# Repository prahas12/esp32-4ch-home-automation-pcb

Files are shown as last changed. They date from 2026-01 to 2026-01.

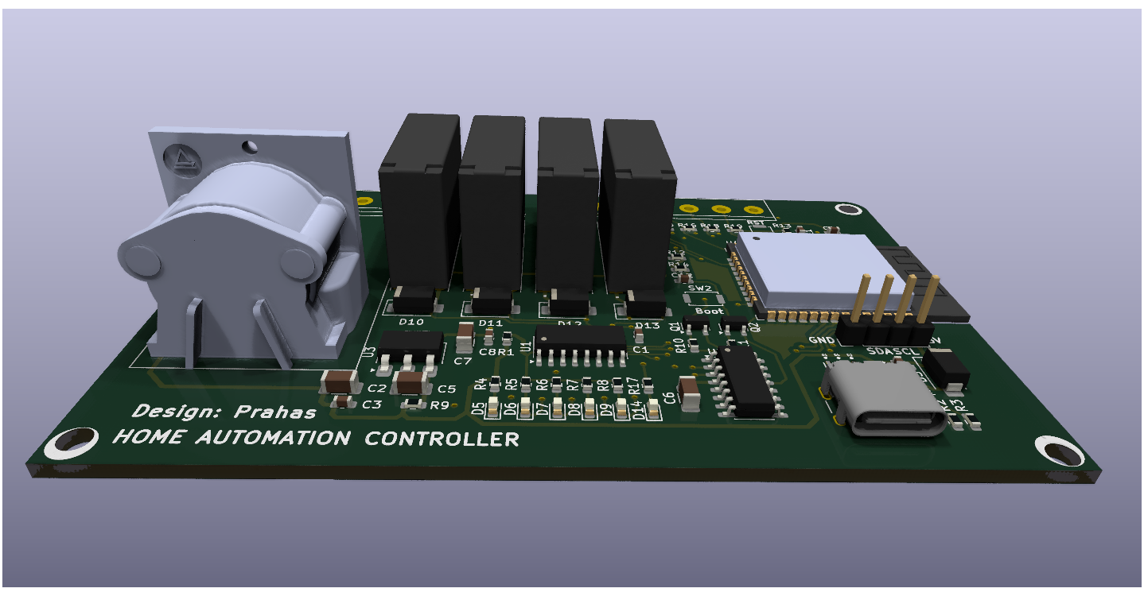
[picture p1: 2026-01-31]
home_automation.png

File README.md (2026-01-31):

# 4-Channel Home Automation PCB using ESP32

This repository contains the hardware design files for a **4-channel home automation system based on ESP32**, designed for reliable and safe control of electrical appliances using Wi-Fi.

The project focuses on practical IoT hardware design, including relay isolation, opto-isolated inputs, and an onboard AC-to-DC power supply.

---

## 🔧 Features

- ESP32-based Wi-Fi control (Web Server & MQTT supported)
- 4-channel relay outputs for AC appliance control
- Opto-isolated inputs for safe external switch interfacing
- Onboard AC-to-DC power module (HLK-PM03 or equivalent)
- Compact 2-layer PCB suitable for enclosure mounting
- Status LEDs for power and relay indication

---

## ⚙️ Hardware Used

- ESP32-WROOM-32 (Wi-Fi + Bluetooth MCU)
- 4 × SPDT Relays (5V)
- Optocouplers for isolated switch inputs
- AC to DC power module (HLK-PM03 or equivalent)
- Screw terminals for AC loads and inputs
- Discrete driver transistors, resistors, and protection components

---

## 🛠️ PCB Design Details

- Designed using **KiCad**
- 2-layer PCB for cost efficiency
- Proper isolation between high-voltage (AC) and low-voltage (ESP32) sections
- Wide copper traces for relay current handling
- Through-hole components used where mechanical strength is required

---

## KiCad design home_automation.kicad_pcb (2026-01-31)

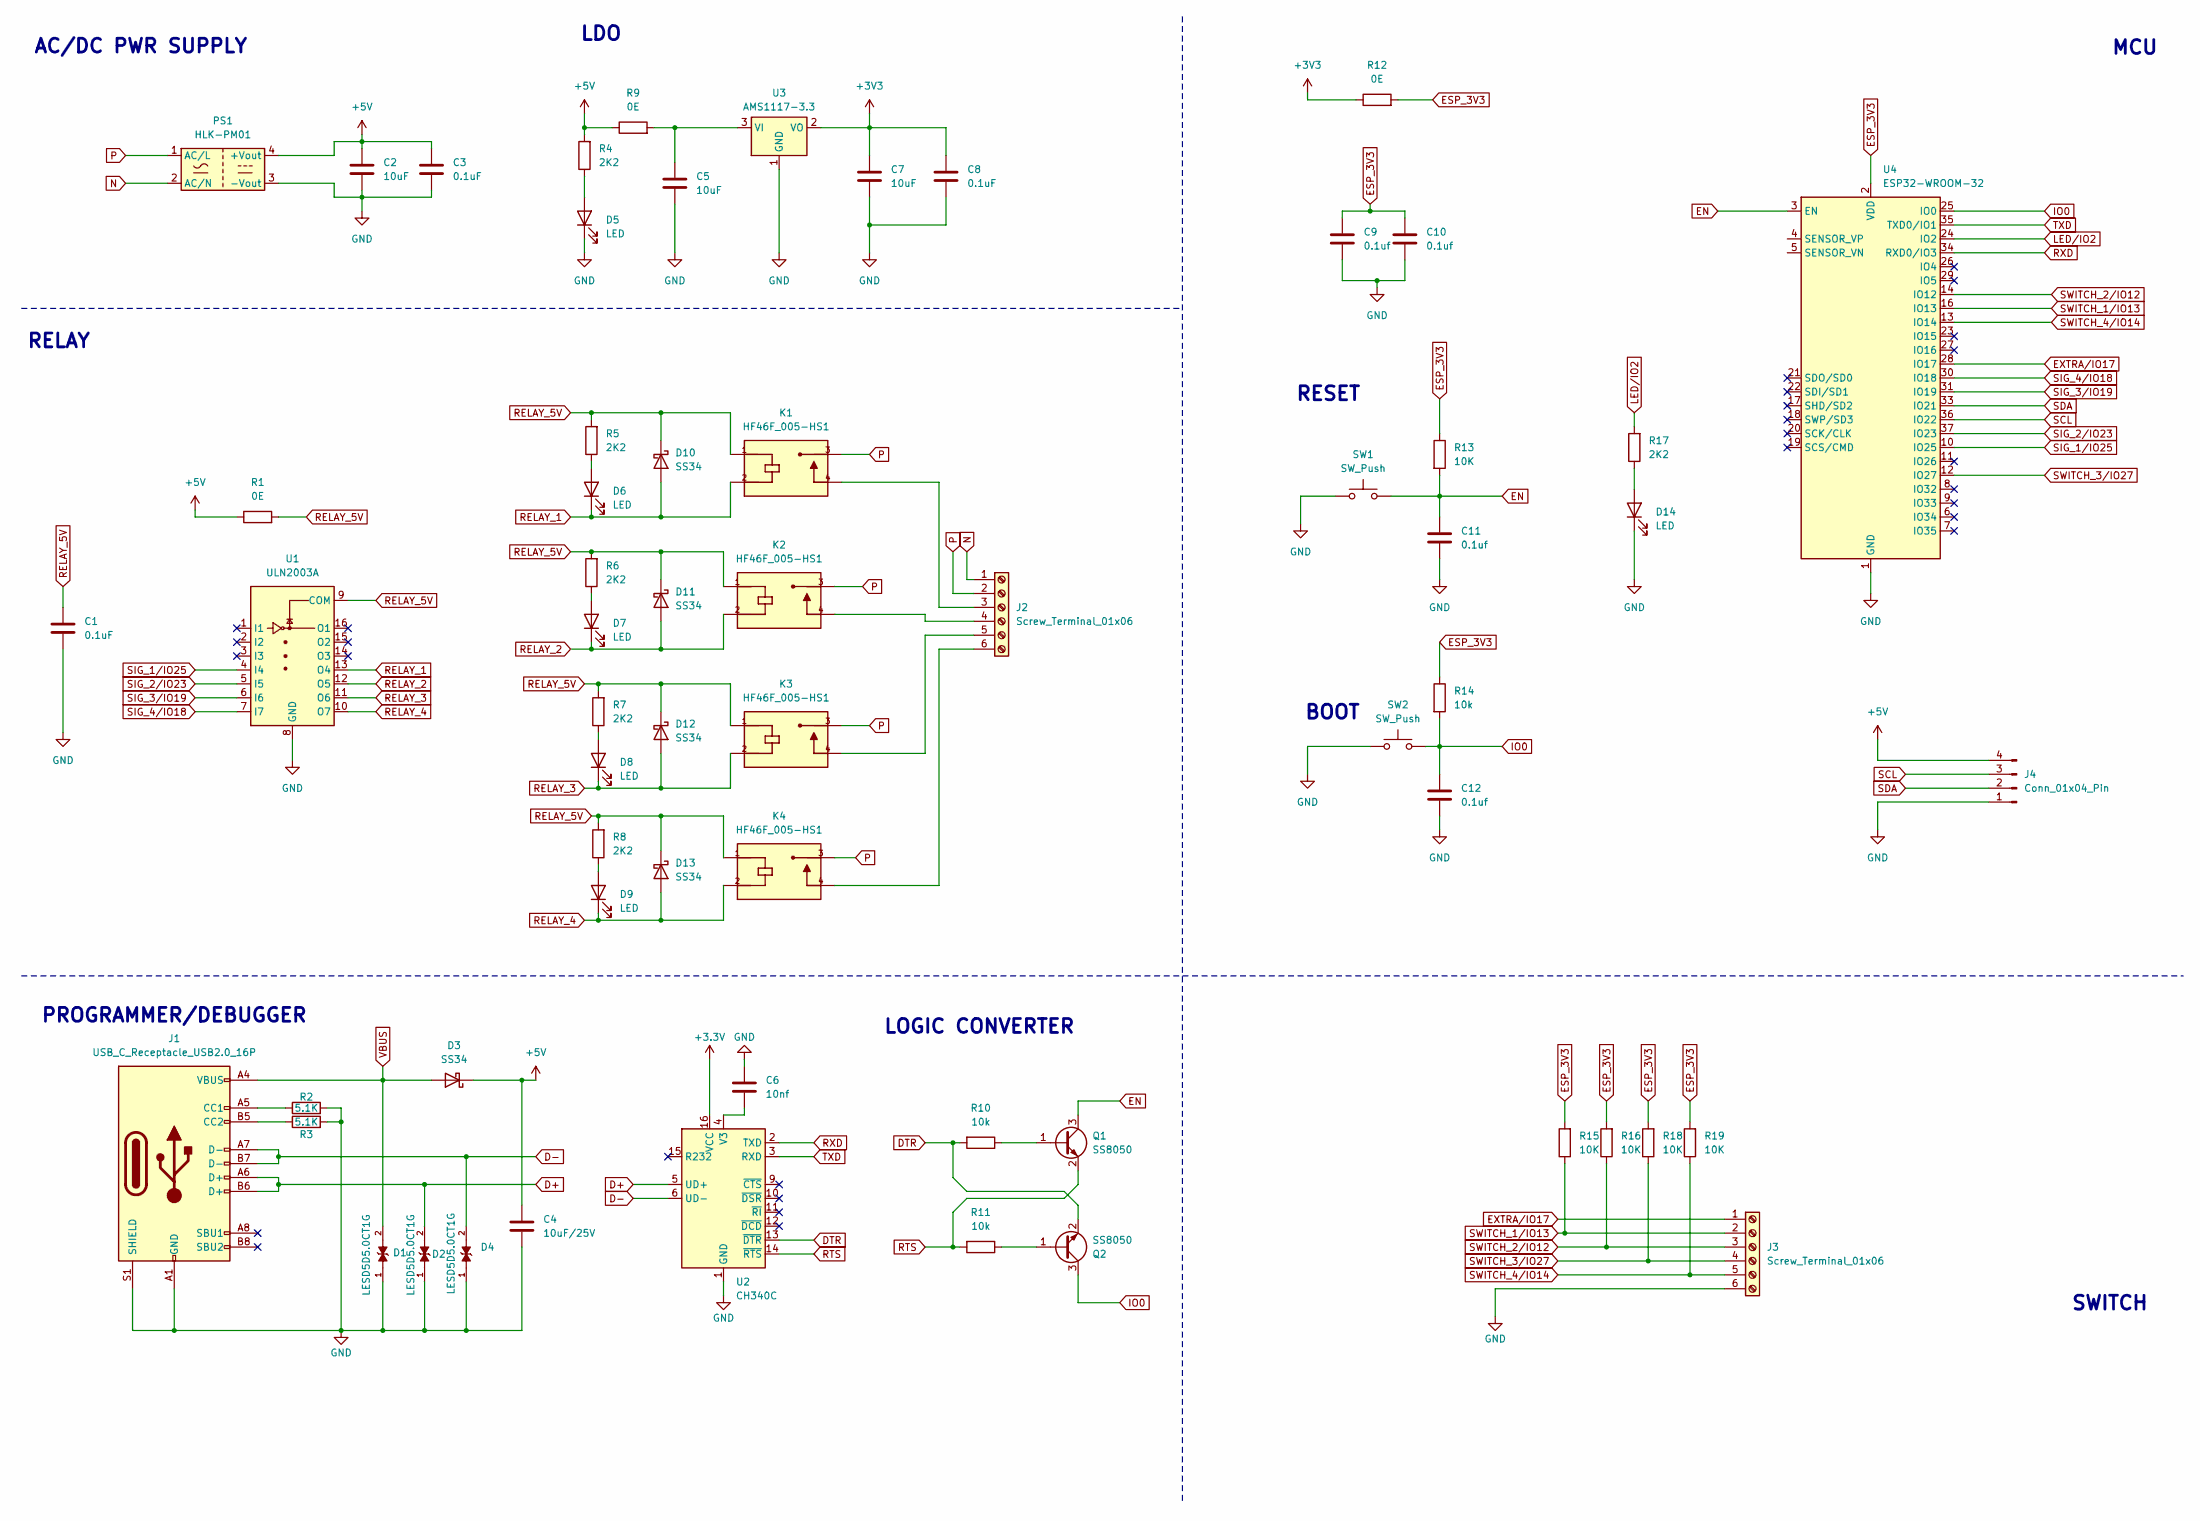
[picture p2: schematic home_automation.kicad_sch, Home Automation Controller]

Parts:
C1, C3, C8: 0.1uF; C_0603_1608Metric
C2, C5, C7: 10uF; C_1206_3216Metric
C4: 10uF/25V; C_0603_1608Metric
C6: 10nf; C_1206_3216Metric
C9, C10, C11, C12: 0.1uf; C_0603_1608Metric
D1, D2, D4: LESD5D5.0CT1G; TVS_LESD5D5.0CT1G; PARTREV O
D3, D10, D11, D12, D13: SS34; D_SMA
D5, D6, D7, D8, D9, D14: LED; LED_0603_1608Metric
J1: USB_C_Receptacle_USB2.0_16P; USB_C_Receptacle_HCTL_HC-TYPE-C-16P-01A
J2, J3: Screw_Terminal_01x06; TerminalBlock_bornier-6_P5.08mm
J4: Conn_01x04_Pin; PinHeader_1x04_P2.54mm_Vertical
K1, K2, K3, K4: HF46F_005-HS1; RELAY_HF46F_005-HS1; PARTREV 1.00
PS1: HLK-PM01; Converter_ACDC_Hi-Link_HLK-PMxx
Q1, Q2: SS8050; SOT-23
R1, R9, R12: 0E; R_0603_1608Metric
R2, R3: 5.1K; R_0603_1608Metric
R4, R5, R6, R7, R8, R17: 2K2; R_0603_1608Metric
R10, R11, R14: 10k; R_0603_1608Metric
R13, R15, R16, R18, R19: 10K; R_0603_1608Metric
SW1, SW2: SW_Push; SW_Push_SPST_NO_Alps_SKRK
U1: ULN2003A; SOIC-16_3.9x9.9mm_P1.27mm
U2: CH340C; SOIC-16_3.9x9.9mm_P1.27mm
U3: AMS1117-3.3; SOT-223-3_TabPin2
U4: ESP32-WROOM-32

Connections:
+3.3V: U2.16 (VCC)
+3V3: C7.1, C8.1, R12.1, U3.2 (VO)
+5V: C2.1, C3.1, C4.1, D3.1 (K), J4.4, PS1.4 (+Vout), R1.1, R4.2, R9.1
D+: D2.2, J1.A6 (D+), J1.B6 (D+), U2.5 (UD+)
D-: D4.2, J1.A7 (D-), J1.B7 (D-), U2.6 (UD-)
DTR: Q2.2 (E), R10.2, U2.13 (~DTR)
EN: C11.1, Q1.3 (C), R13.2, SW1.2, U4.3 (EN)
ESP_3V3: C9.1, C10.1, R12.2, R13.1, R14.1, R15.2, R16.2, R18.2, R19.2, U4.2 (VDD)
EXTRA/IO17: J3.1, U4.28 (IO17)
GND: C1.2, C2.2, C3.2, C4.2, C5.2, C6.1, C7.2, C8.2, C9.2, C10.2, C11.2, C12.2, D1.1, D2.1, D4.1, D5.1 (K), D14.1 (K), J1.A1 (GND), J1.A12 (GND), J1.B1 (GND), J1.B12 (GND), J1.S1 (SHIELD), J3.6, J4.1, PS1.3 (-Vout), R2.2, R3.2, SW1.1, SW2.1, U1.8 (GND), U2.1 (GND), U3.1 (GND), U4.1 (GND), U4.15 (GND), U4.38 (GND), U4.39 (GND)
IO0: C12.1, Q2.3 (C), R14.2, SW2.2, U4.25 (IO0)
LED/IO2: R17.2, U4.24 (IO2)
N: J2.1, PS1.2 (AC/N)
unnamed: D5.2 (A), R4.1
unnamed: D6.2 (A), R5.1
unnamed: D7.2 (A), R6.1
unnamed: D8.2 (A), R7.1
unnamed: D9.2 (A), R8.1
unnamed: D14.2 (A), R17.1
unnamed: J1.A5 (CC1), R2.1
unnamed: J1.B5 (CC2), R3.1
unnamed: J2.3, K1.4
unnamed: J2.4, K2.4
unnamed: J2.5, K3.4
unnamed: J2.6, K4.4
unnamed: Q1.1 (B), R10.1
unnamed: Q2.1 (B), R11.1
unnamed: C6.2, U2.4 (V3)
unnamed: C5.1, R9.2, U3.3 (VI)
P: J2.2, K1.3, K2.3, K3.3, K4.3, PS1.1 (AC/L)
RELAY_1: D6.1 (K), D10.2 (A), K1.2, U1.13 (O4)
RELAY_2: D7.1 (K), D11.2 (A), K2.2, U1.12 (O5)
RELAY_3: D8.1 (K), D12.2 (A), K3.2, U1.11 (O6)
RELAY_4: D9.1 (K), D13.2 (A), K4.2, U1.10 (O7)
RELAY_5V: C1.1, D10.1 (K), D11.1 (K), D12.1 (K), D13.1 (K), K1.1, K2.1, K3.1, K4.1, R1.2, R5.2, R6.2, R7.2, R8.2, U1.9 (COM)
RTS: Q1.2 (E), R11.2, U2.14 (~RTS)
RXD: U2.2 (TXD), U4.34 (RXD0/IO3)
SCL: J4.3, U4.36 (IO22)
SDA: J4.2, U4.33 (IO21)
SIG_1/IO25: U1.4 (I4), U4.10 (IO25)
SIG_2/IO23: U1.5 (I5), U4.37 (IO23)
SIG_3/IO19: U1.6 (I6), U4.31 (IO19)
SIG_4/IO18: U1.7 (I7), U4.30 (IO18)
SWITCH_1/IO13: J3.2, R15.1, U4.16 (IO13)
SWITCH_2/IO12: J3.3, R16.1, U4.14 (IO12)
SWITCH_3/IO27: J3.4, R18.1, U4.12 (IO27)
SWITCH_4/IO14: J3.5, R19.1, U4.13 (IO14)
TXD: U2.3 (RXD), U4.35 (TXD0/IO1)
VBUS: D1.2, D3.2 (A), J1.A4 (VBUS), J1.A9 (VBUS), J1.B4 (VBUS), J1.B9 (VBUS)

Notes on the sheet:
AC/DC PWR SUPPLY
RESET
BOOT
PROGRAMMER/DEBUGGER
LDO
SWITCH
LOGIC CONVERTER
MCU
RELAY

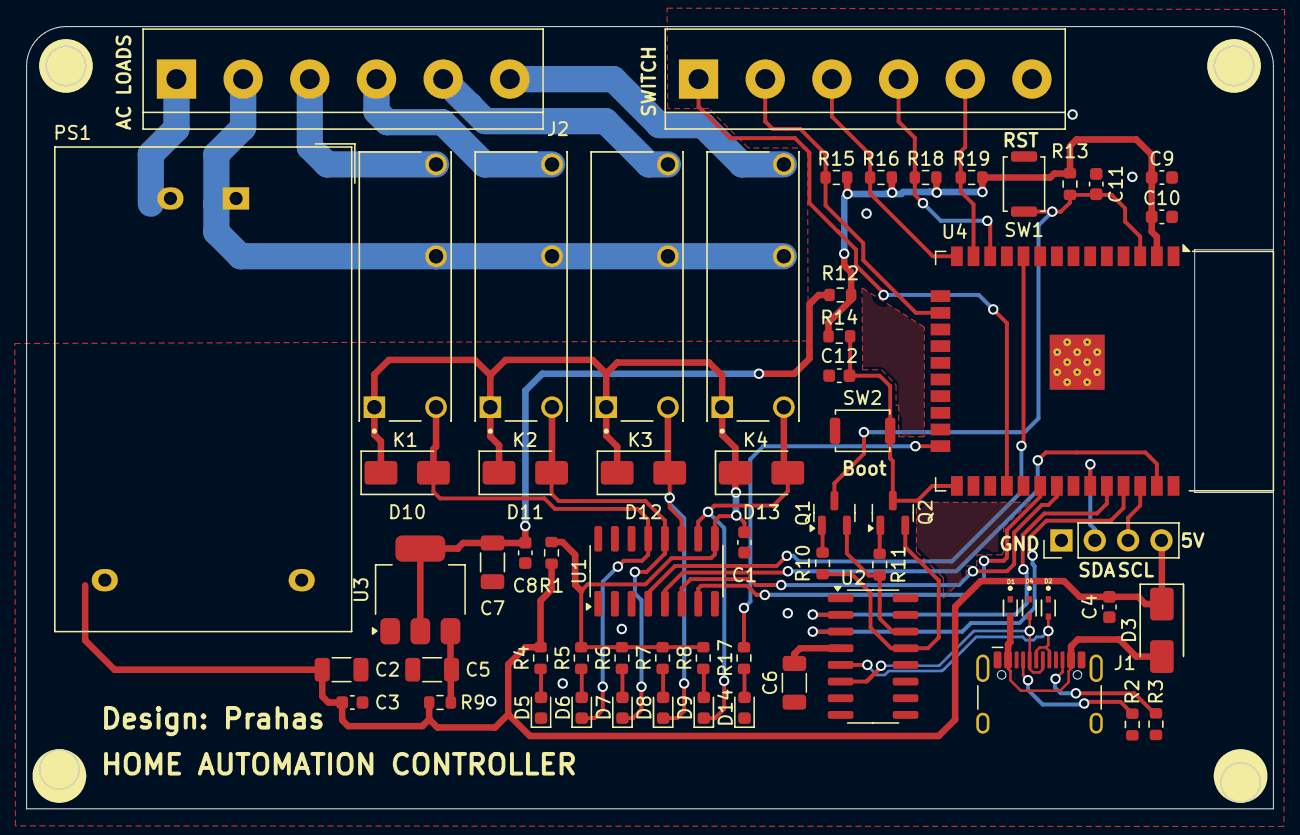
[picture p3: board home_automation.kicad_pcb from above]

Board: 2 copper layers, 95.0 x 59.6 mm, 62 parts (0 on the bottom side), 48 nets.
